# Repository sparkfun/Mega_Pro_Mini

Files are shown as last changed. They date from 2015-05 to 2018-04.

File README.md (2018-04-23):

**NOTE:** *This product has been retired from our catalog. If you are looking for more up-to-date info, please check out some of these resources to see how other users are still hacking and improving on this product.*
* *[SparkFun Forum](https://forum.sparkfun.com/)*
* *[Comments Here on GitHub](https://github.com/sparkfun/Mega_Pro_Mini/issues)*
* *[IRC Channel](https://www.sparkfun.com/news/263)*

SparkFun Mega Pro Mini - 3.3V
========================================

SparkFun Mega Pro Mini - 3.3V

[*SparkFun Mega Pro Mini - 3.3V (DEV-10743)*](https://www.sparkfun.com/products/10743)

 This is a 3.3V microcontroller running a version of the stk500v2 bootloader at 8MHz. 
 In order to shrink the Mega Pro down to its minimum footprint, we’ve condensed the board layout, removed the barrel jack footprint and replaced the traditional Arduino-style headers with compact vertical JST connectors.

 Repository Contents
-------------------

* **/Hardware** - Eagle design files (.brd, .sch)
* **/Production** - Production panel files (.brd)

Documentation
--------------
* **[Board Definition Files](https://github.com/sparkfun/Arduino_Boards)** - Board Definition files for Mega Pro Mini. 
* **[SparkFun Fritzing repo](https://github.com/sparkfun/Fritzing_Parts)** - Fritzing diagrams for SparkFun products.
* **[SparkFun 3D Model repo](https://github.com/sparkfun/3D_Models)** - 3D models of SparkFun products. 

License Information
-------------------
This product is _**open source**_! 

The **hardware** is released under [Creative Commons ShareAlike 4.0 International](https://creativecommons.org/licenses/by-sa/4.0/).

Please use, reuse, and modify these files as you see fit. Please maintain attribution to SparkFun Electronics and release anything derivative under the same license.

Distributed as-is; no warranty is given.

- Your friends at SparkFun.

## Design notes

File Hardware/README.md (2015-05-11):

SparkFun <PRODUCT NAME> Design Files
=====================================

The .sch and .brd files hare are Eagle CAD schematic and PCB design files from SparkFun Electronics.
A freeware version of Eagle can be found [here](http://www.cadsoftusa.com/download-eagle/freeware/). 

License
---------
This product is open source! 
The hardware is released under [Creative Commons ShareAlike 4.0 International](https://creativecommons.org/licenses/by-sa/4.0/).

Please use, reuse, and modify these files as you see fit. Please maintain attribution to SparkFun Electronics and release anything derivative under the same license.

Distributed as-is; no warranty is given.

- Your friends at SparkFun.

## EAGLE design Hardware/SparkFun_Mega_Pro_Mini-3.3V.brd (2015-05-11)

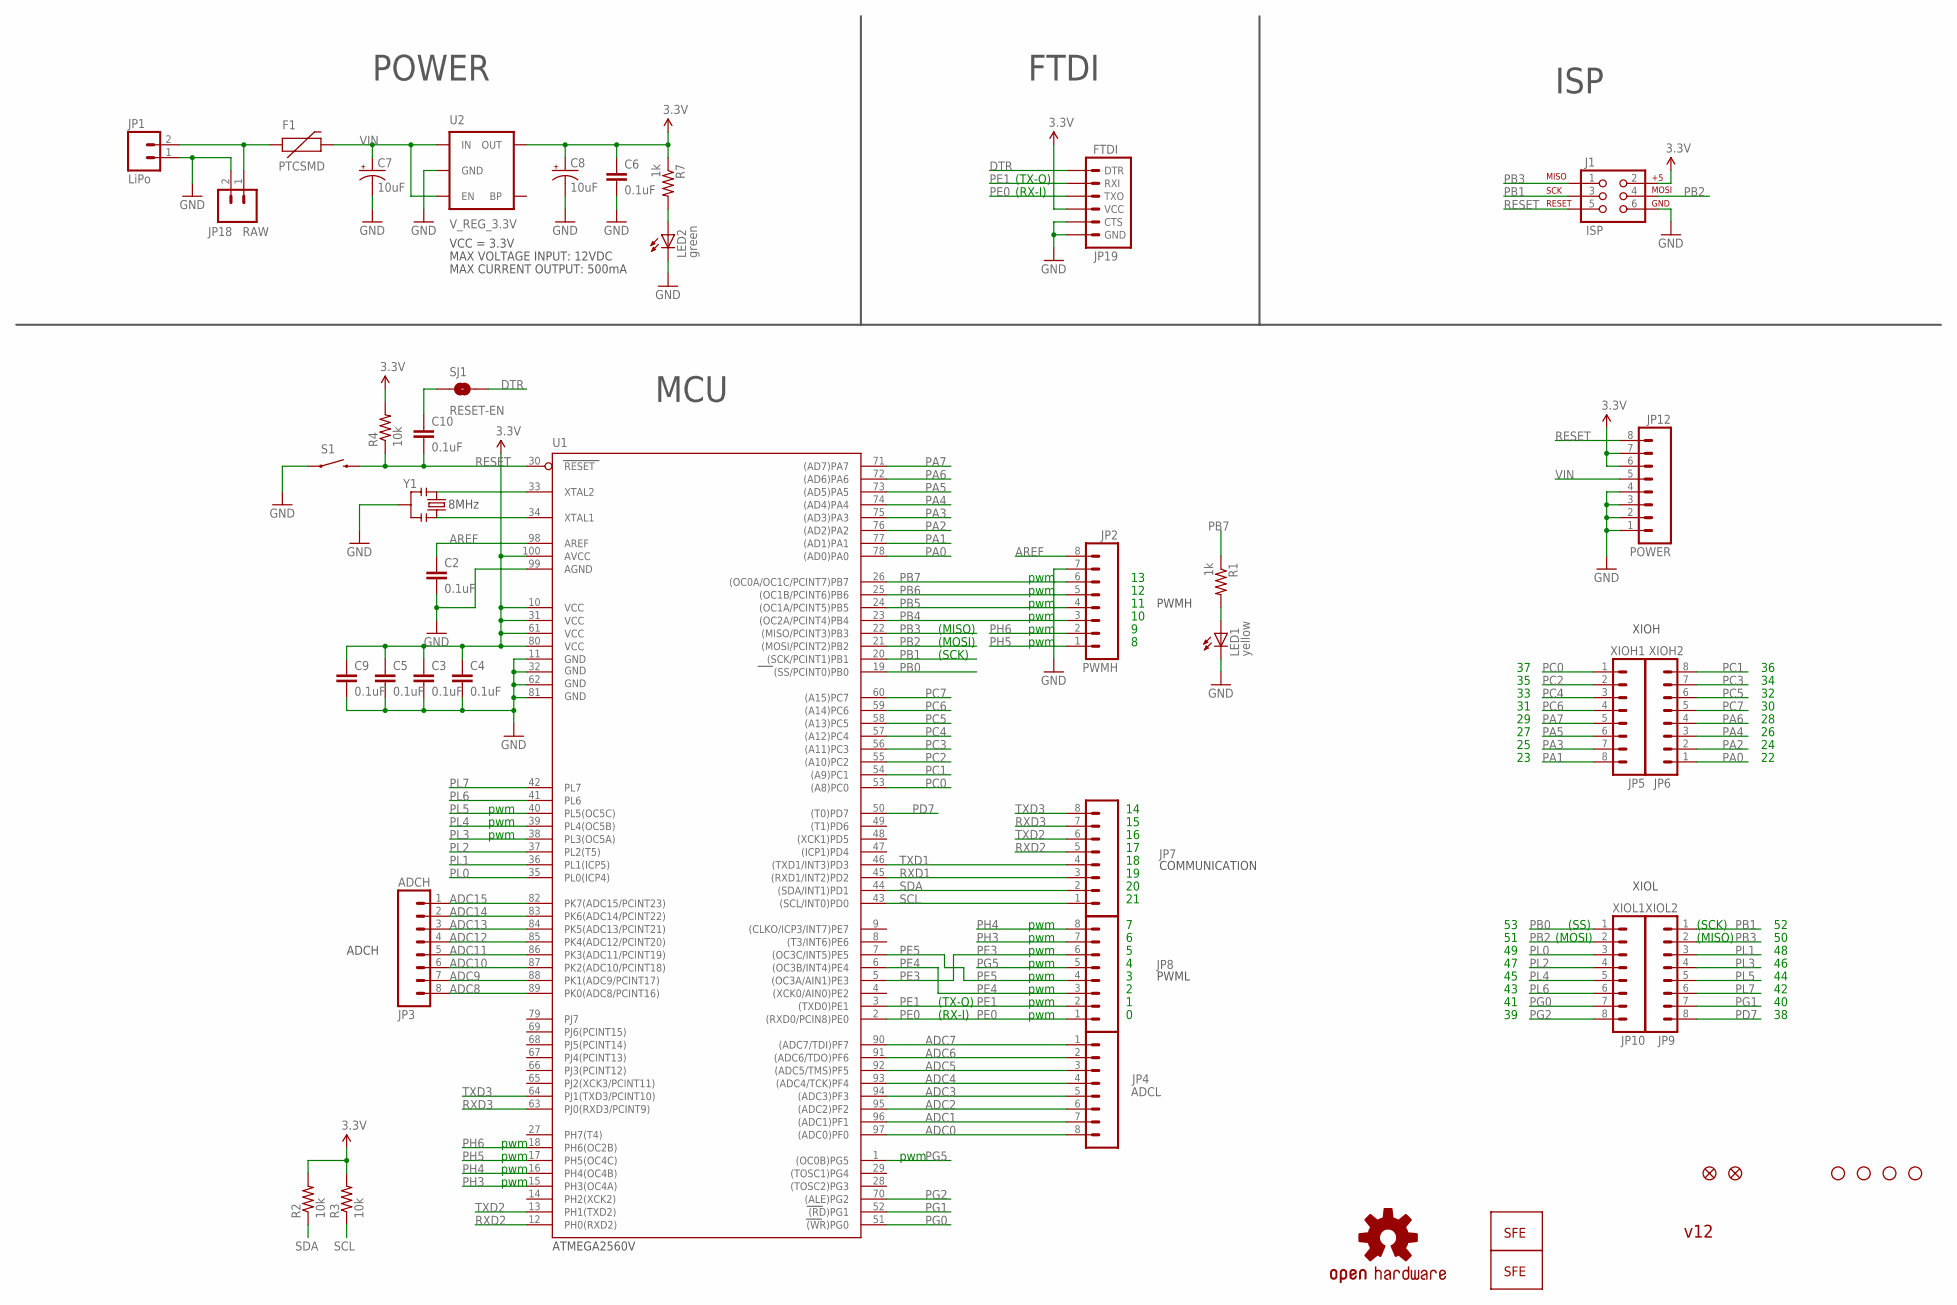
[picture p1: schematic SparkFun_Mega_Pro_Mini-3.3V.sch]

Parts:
C2, C3, C4, C5, C6, C9, C10: 0.1uF; 0402-CAP
C7, C8: 10uF; EIA3216
F1: PTCSMD; PTC-1206
J1: ISP; 2X3
JP1: LiPo; JST-2-SMD
JP2: PWMH; BM08B-SRSS-TB
JP3: ADCH; BM08B-SRSS-TB
JP4: ADCL; BM08B-SRSS-TB
JP5: XIOH1; BM08B-SRSS-TB
JP6: XIOH2; BM08B-SRSS-TB
JP7: COMM; BM08B-SRSS-TB
JP8: PWML; BM08B-SRSS-TB
JP9: XIOL2; BM08B-SRSS-TB
JP10: XIOL1; BM08B-SRSS-TB
JP11, JP13, JP14, JP15: STAND-OFF
JP12: POWER; BM08B-SRSS-TB
JP16: LOGO-SFENEW; SFE-NEW-WEBLOGO
JP17: LOGO-SFESK; SFE-LOGO-FLAME
JP18: RAW; 1X02
JP19: FTDI; 1X06-SMD
JP20, JP21: FIDUCIAL1X2.5; FIDUCIAL-1X2.5
LED1: yellow; LED-0603
LED2: green; LED-0603
R1, R7: 1k; 0402-RES
R2, R3, R4: 10k; 0402-RES
S1: SWITCH-MOMENTARY-2SMD; TACTILE_SWITCH_SMD
SJ1: RESET-EN; SJ_2S
U1: ATMEGA2560AU; TQFP100
U2: V_REG_3.3V; SOT23-5
U$9: OSHW-LOGOL; OSHW-LOGO-L
Y1: RESONATORSMD; RESONATOR-SMD

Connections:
3.3V: C3.1, C4.1, C5.1, C6.1, C8.A (+), C9.1, J1.2, JP12.6, JP12.7, JP19.4 (VCC), R2.2, R3.2, R4.2, R7.1, U1.10 (VCC), U1.31 (VCC1), U1.61 (VCC2), U1.80 (VCC3), U1.100 (AVCC), U2.5 (OUT)
ADC0: JP4.8, U1.97 ((ADC0)PF0)
ADC1: JP4.7, U1.96 ((ADC1)PF1)
ADC2: JP4.6, U1.95 ((ADC2)PF2)
ADC3: JP4.5, U1.94 ((ADC3)PF3)
ADC4: JP4.4, U1.93 ((ADC4/TCK)PF4)
ADC5: JP4.3, U1.92 ((ADC5/TMS)PF5)
ADC6: JP4.2, U1.91 ((ADC6/TDO)PF6)
ADC7: JP4.1, U1.90 ((ADC7/TDI)PF7)
ADC8: JP3.8, U1.89 (PK0(ADC8/PCINT16))
ADC9: JP3.7, U1.88 (PK1(ADC9/PCINT17))
ADC10: JP3.6, U1.87 (PK2(ADC10/PCINT18))
ADC11: JP3.5, U1.86 (PK3(ADC11/PCINT19))
ADC12: JP3.4, U1.85 (PK4(ADC12/PCINT20))
ADC13: JP3.3, U1.84 (PK5(ADC13/PCINT21))
ADC14: JP3.2, U1.83 (PK6(ADC14/PCINT22))
ADC15: JP3.1, U1.82 (PK7(ADC15/PCINT23))
AREF: C2.1, JP2.8, U1.98 (AREF)
DTR: JP19.1 (DTR), SJ1.2
GND: C2.2, C3.2, C4.2, C5.2, C6.2, C7.C (-), C8.C (-), C9.2, J1.6, JP1.1, JP2.7, JP12.1, JP12.2, JP12.3, JP12.4, JP18.2, JP19.5 (CTS), JP19.6 (GND), LED1.C, LED2.C, S1.1, U1.11 (GND), U1.32 (GND1), U1.62 (GND2), U1.81 (GND3), U1.99 (AGND), U2.2 (GND), Y1.2
unnamed: F1.1, JP1.2, JP18.1
unnamed: LED1.A, R1.2
unnamed: LED2.A, R7.2
unnamed: U1.34 (XTAL1), Y1.3
unnamed: U1.33 (XTAL2), Y1.1
unnamed: C10.1, SJ1.1
PA0: JP6.1, U1.78 ((AD0)PA0)
PA1: JP5.8, U1.77 ((AD1)PA1)
PA2: JP6.2, U1.76 ((AD2)PA2)
PA3: JP5.7, U1.75 ((AD3)PA3)
PA4: JP6.3, U1.74 ((AD4)PA4)
PA5: JP5.6, U1.73 ((AD5)PA5)
PA6: JP6.4, U1.72 ((AD6)PA6)
PA7: JP5.5, U1.71 ((AD7)PA7)
PB0: JP10.1, U1.19 ((SS/PCINT0)PB0)
PB1: J1.3, JP9.1, U1.20 ((SCK/PCINT1)PB1)
PB2: J1.4, JP10.2, U1.21 ((MOSI/PCINT2)PB2)
PB3: J1.1, JP9.2, U1.22 ((MISO/PCINT3)PB3)
PB4: JP2.3, U1.23 ((OC2A/PCINT4)PB4)
PB5: JP2.4, U1.24 ((OC1A/PCINT5)PB5)
PB6: JP2.5, U1.25 ((OC1B/PCINT6)PB6)
PB7: JP2.6, R1.1, U1.26 ((OC0A/OC1C/PCINT7)PB7)
PC0: JP5.1, U1.53 ((A8)PC0)
PC1: JP6.8, U1.54 ((A9)PC1)
PC2: JP5.2, U1.55 ((A10)PC2)
PC3: JP6.7, U1.56 ((A11)PC3)
PC4: JP5.3, U1.57 ((A12)PC4)
PC5: JP6.6, U1.58 ((A13)PC5)
PC6: JP5.4, U1.59 ((A14)PC6)
PC7: JP6.5, U1.60 ((A15)PC7)
PD7: JP9.8, U1.50 ((T0)PD7)
PE0: JP8.1, JP19.3 (TXO), U1.2 ((RXD0/PCIN8)PE0)
PE1: JP8.2, JP19.2 (RXI), U1.3 ((TXD0)PE1)
PE3: JP8.6, U1.5 ((OC3A/AIN1)PE3)
PE4: JP8.3, U1.6 ((OC3B/INT4)PE4)
PE5: JP8.4, U1.7 ((OC3C/INT5)PE5)
PG0: JP10.7, U1.51 ((WR)PG0)
PG1: JP9.7, U1.52 ((RD)PG1)
PG2: JP10.8, U1.70 ((ALE)PG2)
PG5: JP8.5, U1.1 ((OC0B)PG5)
PH3: JP8.7, U1.15 (PH3(OC4A))
PH4: JP8.8, U1.16 (PH4(OC4B))
PH5: JP2.1, U1.17 (PH5(OC4C))
PH6: JP2.2, U1.18 (PH6(OC2B))
PL0: JP10.3, U1.35 (PL0(ICP4))
PL1: JP9.3, U1.36 (PL1(ICP5))
PL2: JP10.4, U1.37 (PL2(T5))
PL3: JP9.4, U1.38 (PL3(OC5A))
PL4: JP10.5, U1.39 (PL4(OC5B))
PL5: JP9.5, U1.40 (PL5(OC5C))
PL6: JP10.6, U1.41 (PL6)
PL7: JP9.6, U1.42 (PL7)
RESET: C10.2, J1.5, JP12.8, R4.1, S1.3 (2), U1.30 (RESET)
RXD1: JP7.3, U1.45 ((RXD1/INT2)PD2)
RXD2: JP7.5, U1.12 (PH0(RXD2))
RXD3: JP7.7, U1.63 (PJ0(RXD3/PCINT9))
SCL: JP7.1, R3.1, U1.43 ((SCL/INT0)PD0)
SDA: JP7.2, R2.1, U1.44 ((SDA/INT1)PD1)
TXD1: JP7.4, U1.46 ((TXD1/INT3)PD3)
TXD2: JP7.6, U1.13 (PH1(TXD2))
TXD3: JP7.8, U1.64 (PJ1(TXD3/PCINT10))
VIN: C7.A (+), F1.2, JP12.5, U2.1 (IN), U2.3 (EN)

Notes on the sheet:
(SCK)
(MOSI)
(MISO)
(TX-O)
(RX-I)
pwm
(SS)
8MHz
COMMUNICATION
ADCH
PWML
PWMH
XIOH
XIOL
MCU
POWER
FTDI
ATMEGA2560V
ISP
VCC = 3.3V
MAX VOLTAGE INPUT: 12VDC
MAX CURRENT OUTPUT: 500mA
v12

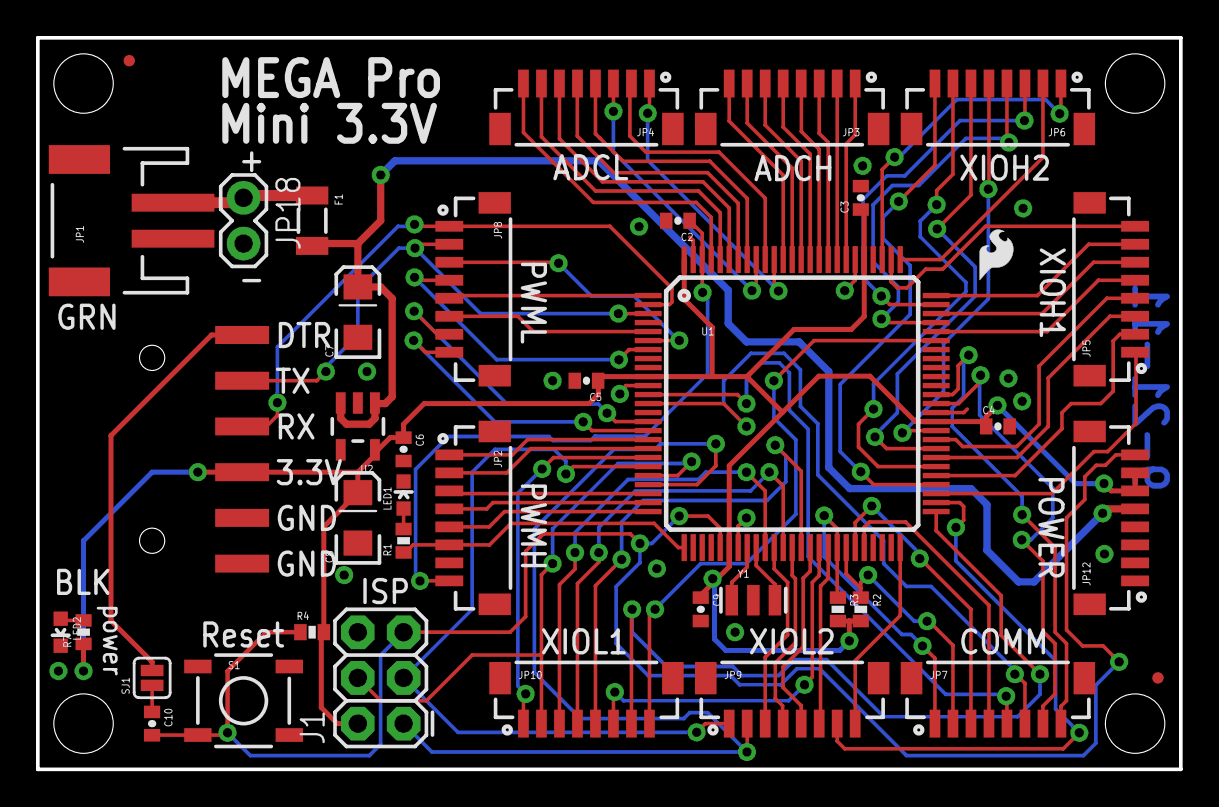
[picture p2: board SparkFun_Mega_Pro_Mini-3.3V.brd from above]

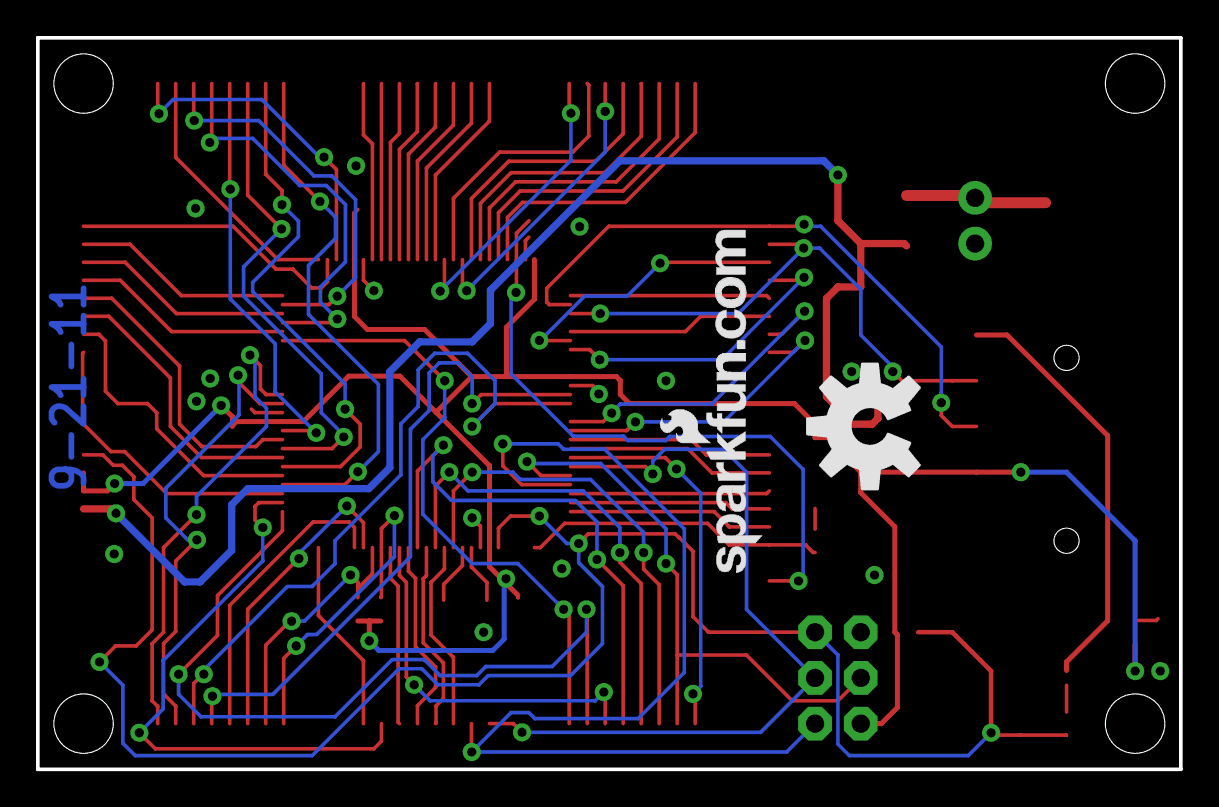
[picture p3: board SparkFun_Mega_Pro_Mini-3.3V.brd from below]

Board: 2 copper layers, 63.5 x 40.6 mm, 45 parts (2 on the bottom side), 82 nets.
